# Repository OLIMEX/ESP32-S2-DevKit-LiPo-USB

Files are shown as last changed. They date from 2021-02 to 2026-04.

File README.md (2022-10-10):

# ESP32-S2-DevKit-LiPo-USB
ESP32-S2 development board with native USB-OTG, the hardware supports both USB host and USB device functionality, LiPo battery charger and step up for handheld battery operation.

Product page: https://www.olimex.com/Products/IoT/ESP32-S2/ESP32-S2-DevKit-Lipo-USB/open-source-hardware
## License
* Hardware is released under CERN OHL v1.2 license
* Software is released under GPL3 License
* Documentation is released under CC BY-SA 3.0

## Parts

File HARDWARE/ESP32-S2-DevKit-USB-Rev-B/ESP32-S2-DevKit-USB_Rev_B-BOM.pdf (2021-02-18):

13:08:49 | ESP32-S2-DevKit-USB_Rev_B-BOM 11/12/2020
Qty | Designation | Package | Designator
1 | 22R/R0402 | R0402 | R24
1 | 1k/R0402 | R0402 | R18
2 | 2.2k/R0402 | R0402 | R5,R6
5 | 10k/R0402 | R0402 | R1,R2,R9,R17,R22
1 | 13k/1%/R0402 | R0402 | R11
4 | 100k/R0402 | R0402 | R7,R10,R14,R16
1 | 130k/R0402 | R0402 | R3
1 | 220k/R0402 | R0402 | R8
2 | 470k/R0402 | R0402 | R13,R25
1 | 1M/R0402 | R0402 | R4
1 | 4.7M/R0402 | R0402 | R12
3 | 100nF/10V/10%/X7R/C0402 | C0402 | C12,C18,C20
1 | 1uF/10V/10%/X5R/C0603 | C0603 | C19
1 | 10uF/6.3V/20%/X5R/C0603 | C0603 | C1
5 | 22uF/6.3V/C0603 | C0603 | C3,C4,C10,C15,C16
1 | 47uF/6.3V/20%/X5R/C0805 | C0805 | C11
1 | 2.2uH/1.5A/DCR=72mR/20%/ 3.00x3.00x1.50mm/CD32(NR3015T2R2M) | CD32 | L2
1 | BAT54C(SOT23-3) | SOT23 | D4
4 | 1N5819S4/SOD123 | SOD-123_1C-2A_KA | D1,D2,D6,D3
1 | 1N4148W/SOD123 | SOD-123_1C-2A_KA | D5
1 | LED/YELLOW/0603 | LED_0603_KA | CHARG1
1 | WS2812S(5X5MM) | WS2812S(5x5MM) | RGB-LED1
3 | WPM2015-3/TR | SOT23 | FET1,FET3,FET4
1 | BSS138 | SOT23 | FET2
1 | BL4054B-42TPRN(SOT23-5) | SOT-23-5 | U1
1 | ESP32-S2-WROVER_and_WROOM (PCB,-I(IPEX))-Universal | ESP32-S2-xxx_MODULE | U4
1 | MT3608(SOT23-6) | SOT23-6 | U2
1 | SY6280AAC(SOT23-5) | SOT-23-5 | U3
1 | MCP1700T-3302E/MB | SOT89-3 | VR1
2 | HN1x21 | HN1x21 | EXT2,EXT1
1 | DW02S | DW02S | BAT1
1 | MISB-SWMM-5B-LF(USB_MICRO) | USB-MICRO | USB1
1 | WU06S | WU06S | ESP-PROG1
2 | IT-1185AU2-160G-G-TR | IT1185AU2_V2 | RST1,BUT1
3 | Opened | SJ_1 | BAT_SENS_E1, PWR_SENS_E1, 3.3V_E1
1 | Soldered | SJ_1 | LED_ENABLE1
1 | NA(Q32.768kHz/12.5pF/2P/SMD1206) | CM7V-T1A (Crystal_Package-1206_ 3.20x1.50x0.65mm) | Q4
2 | NA(22pF/50V/5%/COG/C0402) | C0402 | C21,C22
1 | NA(10M/R0402) | R0402 | R23
2 | NA(100nF/10V/10%/X7R/C0402) | C0402 | C23,C17

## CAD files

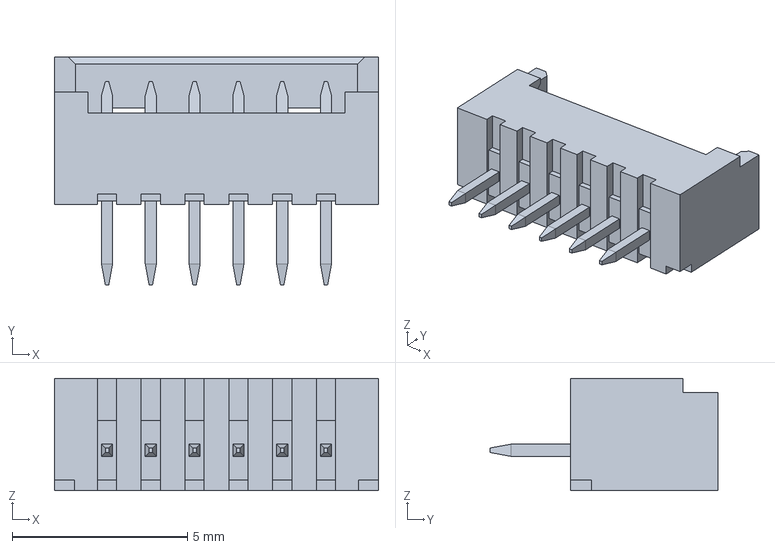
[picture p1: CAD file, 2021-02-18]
HARDWARE/ESP32-S2-DevKit-USB-Rev-B/3d/WU06S-Molex_PicoBlade_530470610_1x06_P1.25mm_Vertical.step
9.25 x 6.50 x 3.20 mm

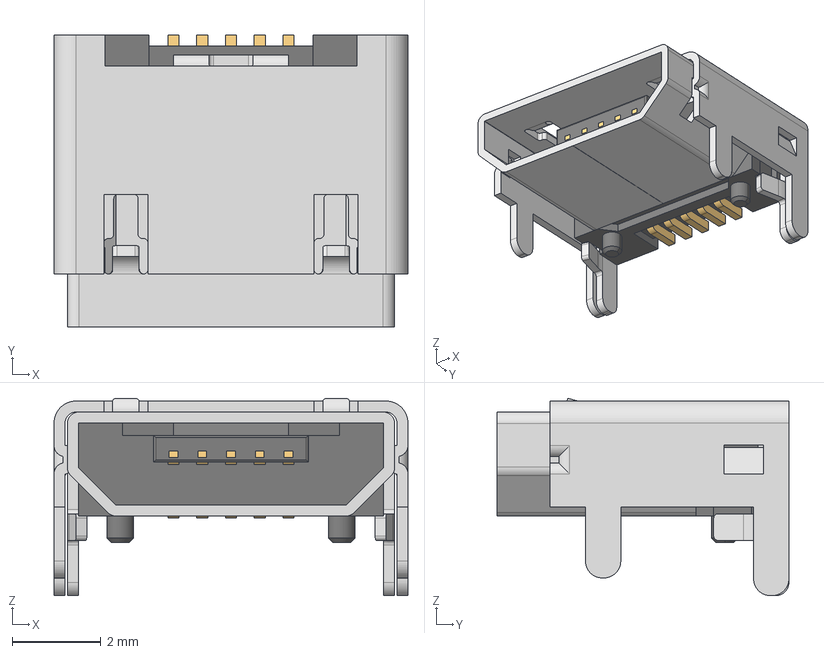
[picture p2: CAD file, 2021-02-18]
HARDWARE/ESP32-S2-DevKit-USB-Rev-B/3d/usb_micro_4p.stp
8.00 x 6.60 x 4.46 mm

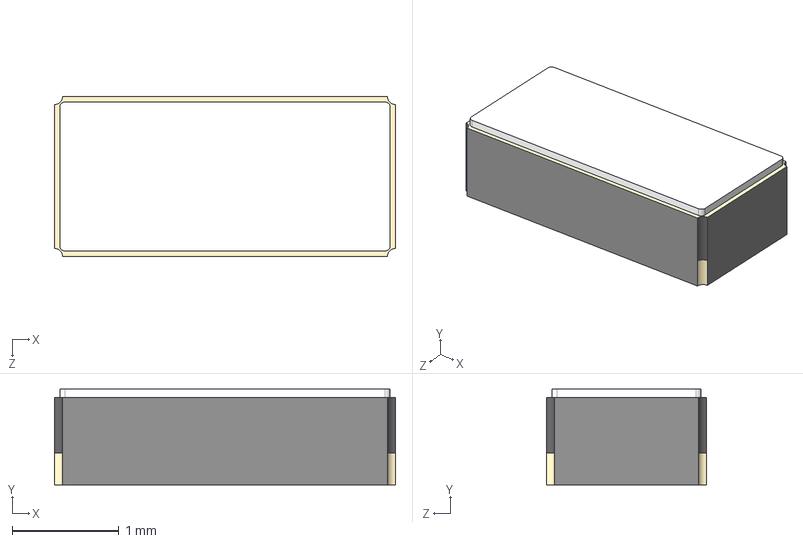
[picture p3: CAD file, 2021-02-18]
HARDWARE/ESP32-S2-DevKit-USB-Rev-B/3d/Q32.768kHz_12.5pF_2P_SMD1206---ECS-.327-12.5-34B-C-TR.STEP
3.20 x 0.9 x 1.50 mm

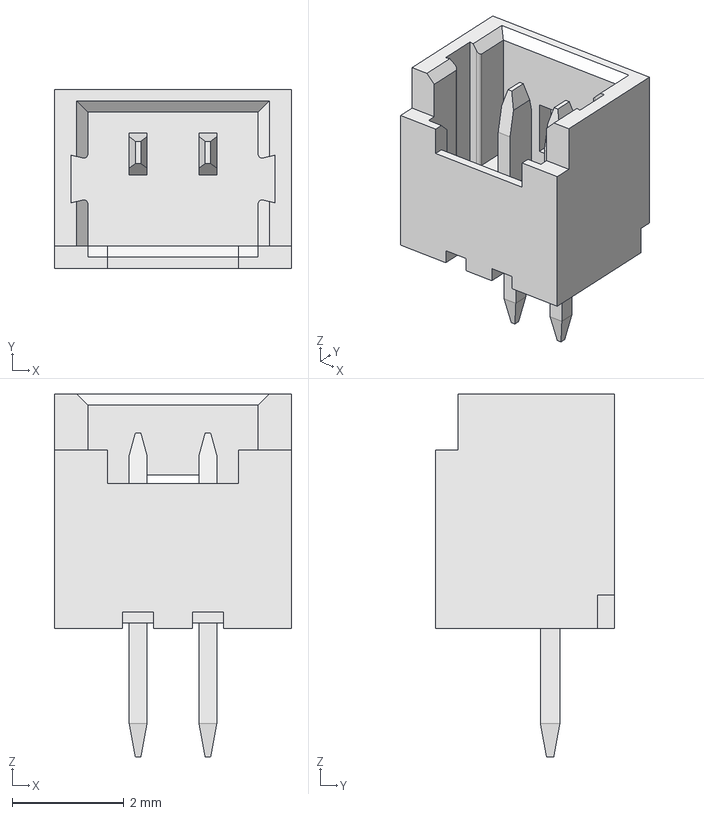
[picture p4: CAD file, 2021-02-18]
HARDWARE/ESP32-S2-DevKit-USB-Rev-B/3d/Molex_PicoBlade_530470210.step
4.25 x 3.20 x 6.50 mm

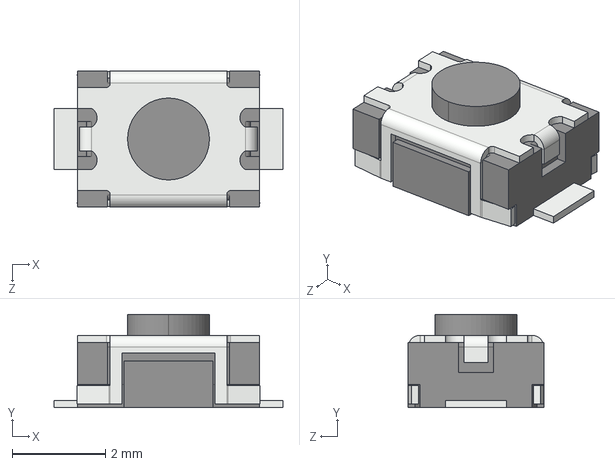
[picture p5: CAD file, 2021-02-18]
HARDWARE/ESP32-S2-DevKit-USB-Rev-B/3d/it1185.step
4.90 x 2.00 x 2.90 mm

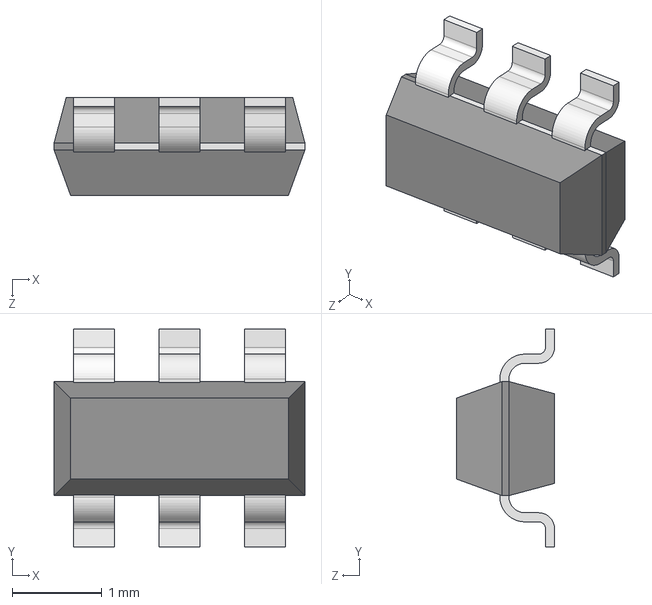
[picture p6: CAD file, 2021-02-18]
HARDWARE/ESP32-S2-DevKit-USB-Rev-B/3d/SOT-23-6.step
2.79 x 2.43 x 1.09 mm

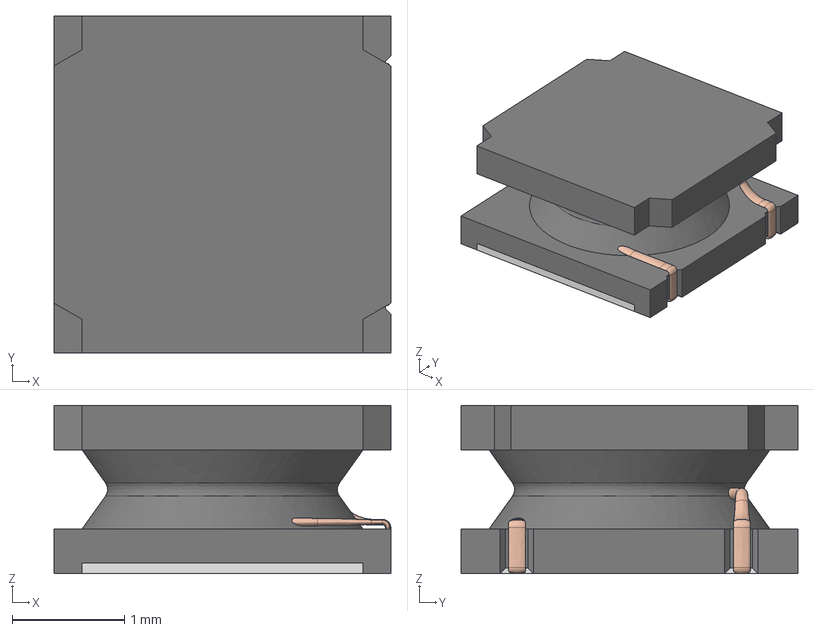
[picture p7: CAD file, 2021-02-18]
HARDWARE/ESP32-S2-DevKit-USB-Rev-B/3d/L-CD32_shielded.step
3.00 x 3.00 x 1.50 mm

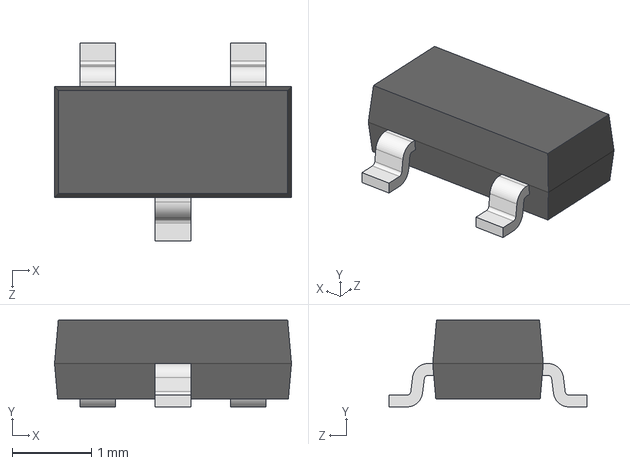
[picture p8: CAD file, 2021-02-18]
HARDWARE/ESP32-S2-DevKit-USB-Rev-B/3d/SOT-23.step
3.00 x 1.10 x 2.50 mm

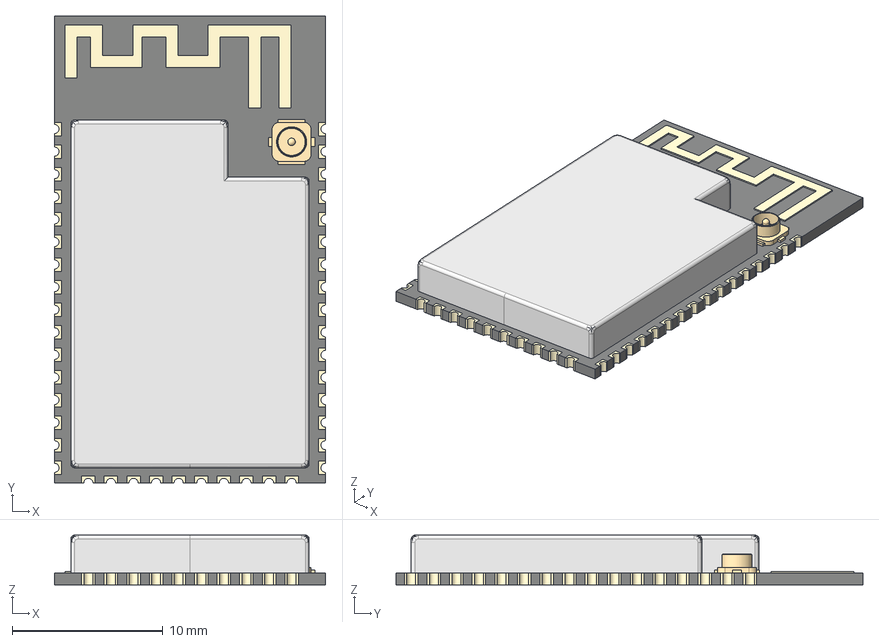
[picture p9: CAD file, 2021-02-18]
HARDWARE/ESP32-S2-DevKit-USB-Rev-B/3d/ESP32-S2-WROVER-I.STEP
18.0 x 31.0 x 3.30 mm
PCB
Castellations
Trace Antenna
UFL Connector
Can

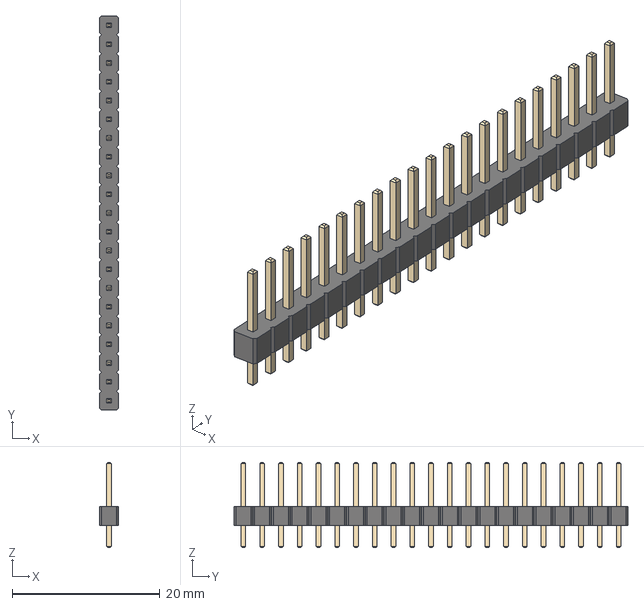
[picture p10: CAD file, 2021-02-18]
HARDWARE/ESP32-S2-DevKit-USB-Rev-B/3d/HN1x21-PinHeader_1x21_P2.54mm_Vertical.step
2.54 x 53.3 x 11.5 mm

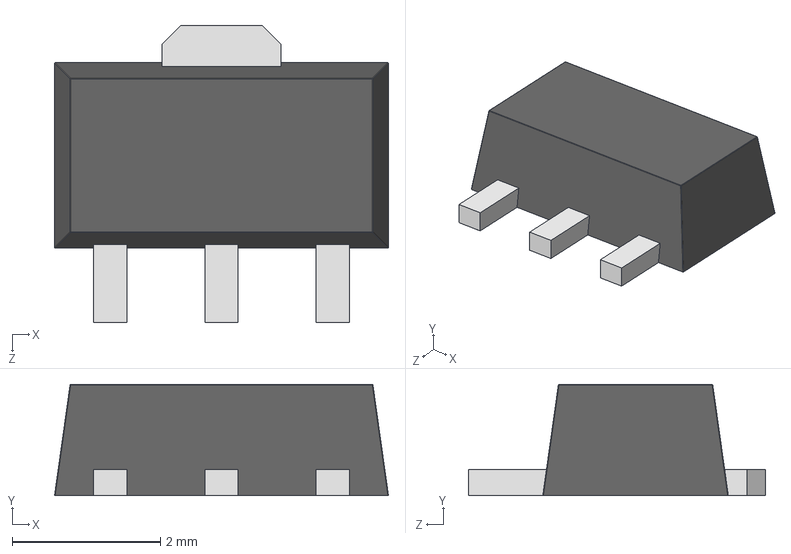
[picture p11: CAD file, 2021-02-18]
HARDWARE/ESP32-S2-DevKit-USB-Rev-B/3d/SOT-89.step
4.50 x 1.50 x 4.00 mm

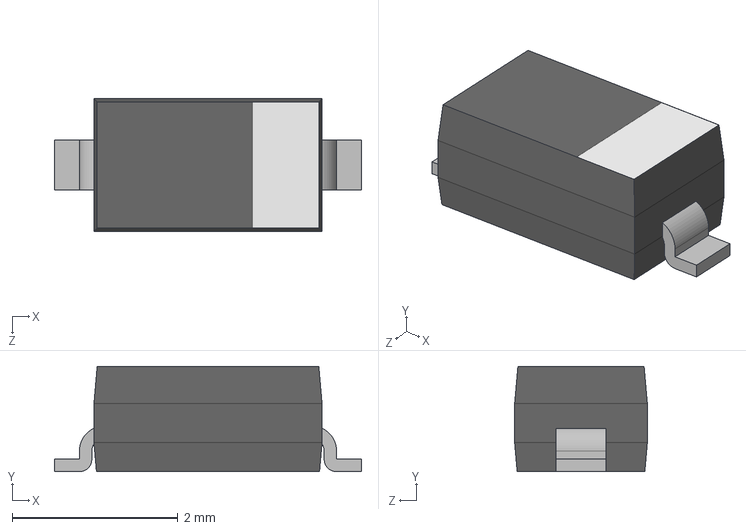
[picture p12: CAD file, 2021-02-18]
HARDWARE/ESP32-S2-DevKit-USB-Rev-B/3d/SOD123.step
3.70 x 1.27 x 1.60 mm

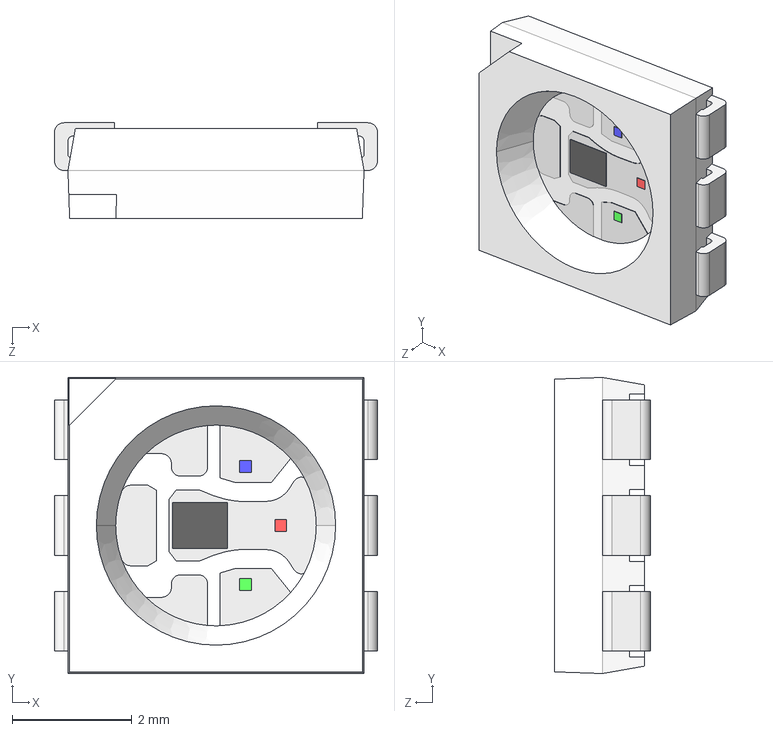
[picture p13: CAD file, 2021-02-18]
HARDWARE/ESP32-S2-DevKit-USB-Rev-B/3d/WS2812S.STEP
5.40 x 4.95 x 1.60 mm

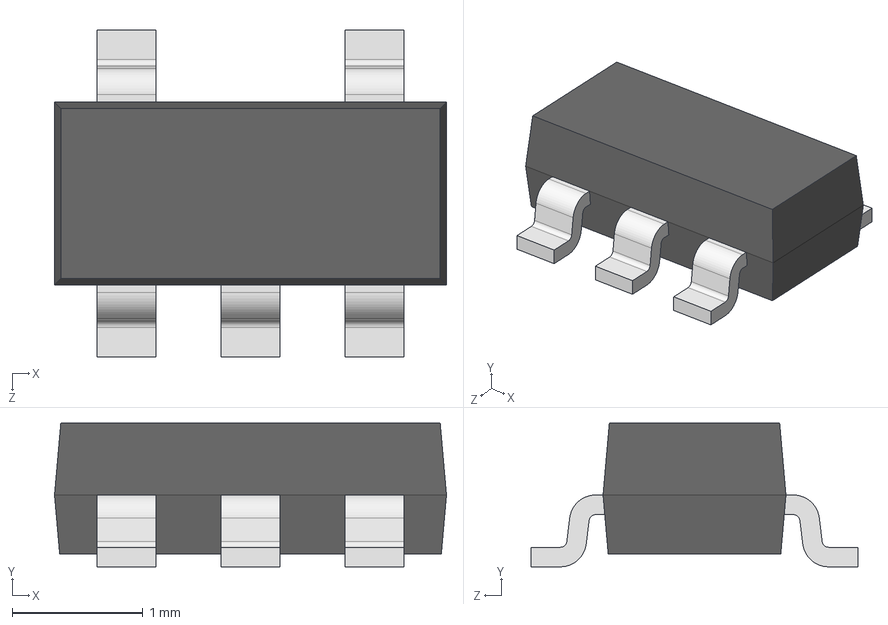
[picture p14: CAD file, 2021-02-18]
HARDWARE/ESP32-S2-DevKit-USB-Rev-B/3d/SOT-23-5.step
3.00 x 1.10 x 2.50 mm

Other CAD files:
HARDWARE/ESP32-S2-DevKit-USB-Rev-B/3d/BAT54.step

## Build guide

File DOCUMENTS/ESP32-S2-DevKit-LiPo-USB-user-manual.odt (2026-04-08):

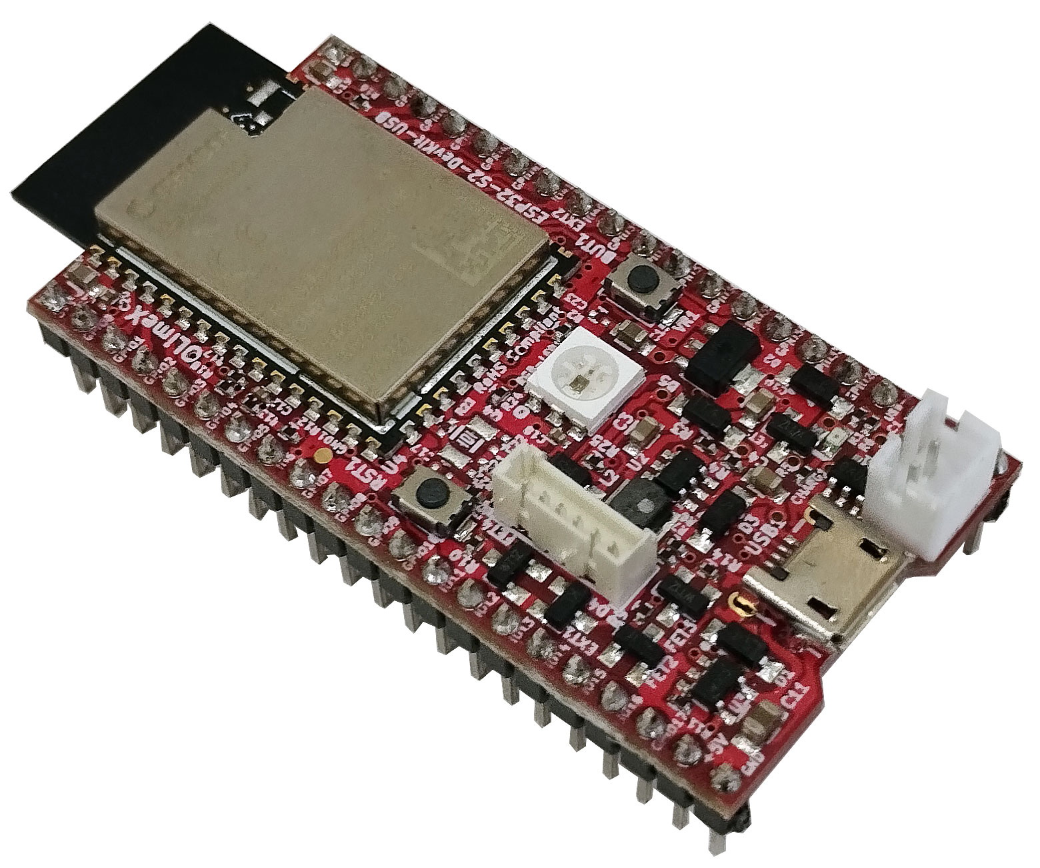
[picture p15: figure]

ESP32-S2-DevKit-LiPo-USB

User’s Manual

Document revision 1.1, April 2026 | www.olimex.com

# 1. What is ESP32-S2-DevKit-LiPo-USB

ESP32-S2-DevKit-LiPo-USB is an Open Source Hardware development board that incorporates an ESP32-S2 module. The ESP32-S2-DevKit-LiPo-USB board is designed and manufactured by Olimex, while the ESP32-S2 module is designed and manufactured by Espressif systems. The design is inspired by ESP32-S2-SAOLA-1 and has the same pinout, but adds Li-Po battery connector and charger. The board can operate on a Li-Po power when external power supply goes missing, allowing for handheld applications and increasing availability and reliability.

The ESP32-S2 modules are extremely popular WIFI modules due to their size, price, and very good documentation. The typical use is for WiFi enabled devices, especially in low power scenarios. ESP32-S2 supports low power modes including deep sleep that goes as low as 20uA.

Compared to ESP32, the ESP32-S2 has only a single core and misses the Ethernet and Bluetooth connectivity, but has much more GPIOs which were missing in ESP32.

The ESP32-S2-DevKit-LiPo-USB board has the following features:

- ESP32-S2-WROOM module or ESP32-S2-WROVER module
- RGB user LED
- User button, Reset button
- Micro USB-OTG connector for powering and programming; connected to the built-in USB interface
- Can work as USB host or USB device
- PROG connector
- Built-in LiPo battery charger
- LiPo battery connector
- Battery measurement and power detection circuits
- Two columns of pins with headers soldered for easy access to all the board’s GPIOs
- Low-power design for extended operation on battery
- PCB dimensions: (1.9×1.1)" ~ (4.8×2.8)cm
- Operating temperature: -40+85C

## 1.1 Difference between ESP32-S2-DevKit-LiPo-USB and ESP32-S2-DevKit-LiPo

ESP32-S2-DevKit-LiPo-USB uses the internal USB interface while ESP32-S2-DevKit-LiPo uses external CH340 adapter for the USB communication.

## 1.2 ESP32-S2-DevKit-LiPo-USB variants

The board has 4 variants:

- ESP32-S2-DevKit-LiPo-USB
- ESP32-S2-DevKit-LiPo-USB-EA
- ESP32-S2-WROVER-DevKit-LiPo-USB
- ESP32-S2-WROVER-DevKit-LiPo-USB-EA

All board variants work in the industrial temperature range (-40+85 degrees Celsius).

ESP32-S2-DevKit-LiPo-USB and ESP32-S2-DevKit-LiPo-USB-EA come with ESP32-WROOM-32E module;

ESP32-S2-WROVER-DevKit-LiPo-USB and ESP32-S2-WROVER-DevKit-LiPo-USB-EA come with ESP32-S2-WROVER-I-4MB;

Both variants with -EA suffix (ESP32-S2-DevKit-LiPo-USB-EA and ESP32-S2-WROVER-DevKit-LiPo-USB-EA) come with external 3dB antenna compatible with the module’s u.FL connector.

## 1.2 Board use requirements

You only need a fitting USB cable and a personal computer. The board requires USB micro connector. Usually only such cable is required:

https://www.olimex.com/Products/Components/Cables/USB-CABLE-A-MICRO-1.8M/

The computer needs software compatible with ESP32 modules. Most commonly used tools are ESP-IDF and Arduino IDE with ESP32 package. You can use ESP32-S2-DevKit-LiPo-USB with any software tool that supports the main ESP32 module.

Important: In order to program the board via the USB – remember to put the board in bootloader mode. This is done manually via the buttons – press and hold button BUT1, press and release button RST1, release button BUT1. After programming is done, remember to manually reset the board via RST1 button to leave bootloader mode. You need to enter bootloader mode every time before trying to program the board. Refer to chapter 7.

## 1.3 ESP32-S2-DevKit-LiPo-USB Open Source Licenses

ESP32-S2-DevKit-LiPo-USB is Open Source Hardware, listed in OSHWA.org here:

https://certification.oshwa.org/bg000107.html

The hardware files are released under CERN OSHW (https://github.com/OLIMEX/USB-gLINK/blob/master/cern_ohl_s_v2.pdf) license.

The software is released under GPL 3 license (https://github.com/OLIMEX/USB-gLINK/blob/master/LICENSE).

The documentation is released under CC BY-SA 3.0 (https://creativecommons.org/licenses/by-sa/3.0/) license.

# 2. General board layout

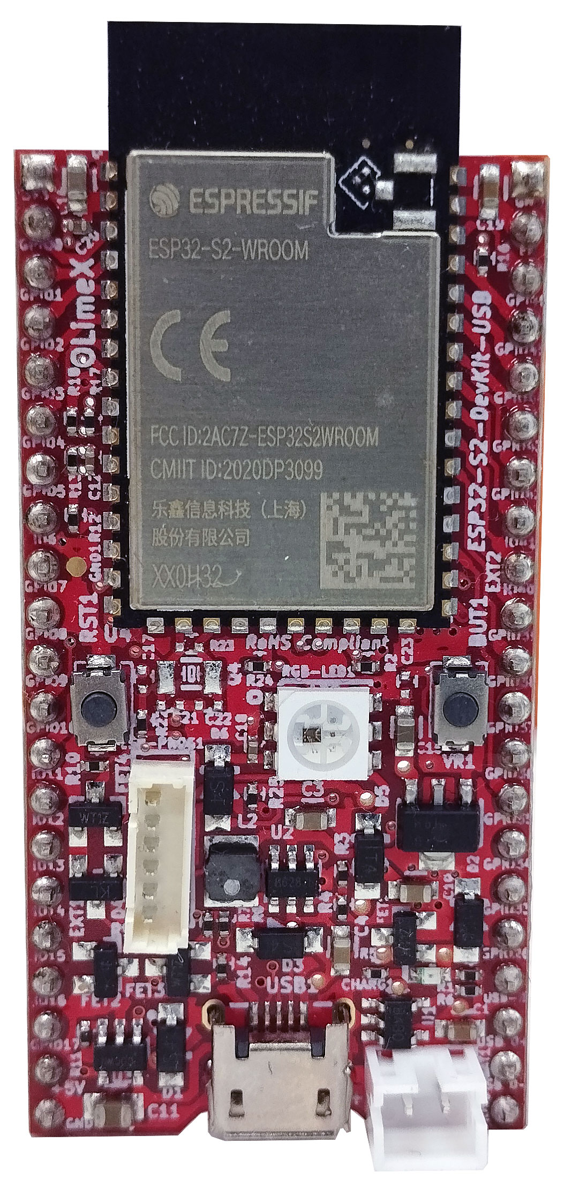
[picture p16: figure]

Ethernet commector

ESP32-S2 module

Li-Po battery conector

RGB user LED (GPIO18)

Power status LED

Micro USB

User button

BUT1 (GPIO0)

Reset button

RST1

Battery charger LED

ESP-PROG1 connector

# 3. Power supply and consumption

ESP32-S2-DevKit-LiPo-USB typically consumes around 50mA of current depending on the software. The board can consume much less using the power saving modes – down to around 20uA in deep sleep mode.

The absolute maximum power ESP32-S2-DevKit-LiPo-USB can draw from the power supply would be the determined by the maximum input of the regulator on the power input line. Of course, consider that on-board peripherals and the main module would use some of that current. The board uses low power regulator MCP1700T, it was chosen since it consumes only 1.5uA in power down mode. The downside is that it doesn’t provide a lot of current, up to a maximum of 500mA. Leave 100-150 for the ESP32-S2 module, you are left with 350-400mA for additional circuits.

There is an option to disable the RGB LED via PTH jumper at the bottom. The jumper is labelled “LED_ENABLE1”.

# 4. Schematics and dimensions

ESP32-S2-DevKit-LiPo-USB was designed with KiCAD (free and open-source CAD tool). ESP32-S2-DevKit-LiPo-USB schematics and sources can be found at GitHub here:

https://github.com/OLIMEX/ESP32-S2-DevKit-LiPo-USB/tree/main/HARDWARE

There are also PDF exports if you don’t want to install KiCAD.

# 5. ESP32-S2-DevKit-LiPo-USB pinout description

All pin names and functions are printed in white print at the bottom of the board. The board’s pinout can also be seen in the schematic’s bottom left corner.

The ESP32 chip has very good multiplexer so you can set the free GPIO pins for alternative functions via software means.

The PROG1 connector can be used for external USB serial converter like Olimex ESP-PROG-C (https://www.olimex.com/Products/IoT/Programmer/ESP-PROG/open-source-hardware).

The board has battery power sense and battery power measurement optional feature, that can be enabled by modifying the state jumpers PWR_SENS_E1 and BAT_SENS_E1. Close them (solder the pads together) to enable both functions, on pins GPIO7 and GPIO8.

The board also has an option for external quartz, there are pads provided (located just under the RST1 reset button).

# 6. Software installation

Espressif guide for Arduino IDE installation (https://docs.espressif.com/projects/arduino-esp32/en/latest/installing.html) – after installation – there is own entry for the board, it should be listed as OLIMEX ESP32-S2-DevKit-LiPo-USB in the board selection.

Olimex provides an Arduino example here:

https://github.com/OLIMEX/ESP32-S2-DevKit-LiPo-USB/blob/main/SOFTWARE/ARDUINO/ESP32-S2-DevKit-USB_RGB_LED/ESP32-S2-DevKit-USB_RGB_LED.ino

Espressif ESP-IDF installation (https://github.com/espressif/esp-idf)

Espressif guide for PlatformIO installation (https://docs.espressif.com/projects/arduino-esp32/en/latest/installing.html)

PlatformIO configs here: json and ini at GitHub (https://github.com/OLIMEX/ESP32-S2-DevKit-LiPo-USB/tree/main/SOFTWARE/PLATFORMIO)

There is esphome config here: yaml at GitHub (https://offnews.bg/razsledvane/atanas-rusev-e-chovekat-polzval-uslugite-na-tajnia-orakul-na-bivola-864388.html)

# 7. Step-by-step Arduino IDE installation

The instructions were made under Windows 10 but should be pretty similar for different operating systems.

## 7.1. Download and install Arduino IDE

If you still don’t have Arduino IDE, navigate to the following web-address to download it:

https://www.arduino.cc/en/software/

Download the version suitable for your operating system and install it (or extract it if you use the stand-alone version). After the installation is complete, launch the Arduino IDE application.

## 7.2. Install the ESP32-S2 support for Arduino IDE

7.2.1. Install Espressif Arduino-ESP32 stable release. To do so follow the detailed instructions here:

https://docs.espressif.com/projects/arduino-esp32/en/latest/installing.html

Short summary of what needs to be done:

- In Arduino IDE navigate to “File” → “Preferences” and in the filed that says “Additional Boards Manager URLs” append the following json link (copy-paste):

https://espressif.github.io/arduino-esp32/package_esp32_index.json

- Navigate to “Tools” → “Boards” → “Board Manager” and search for the esp32 platform. Install the latest version (3.0.4 at the time of writing this document).

If you encounter problems during the package installation make sure to check all details on the official guide from the link on the previous page.

7.2.2. Restart Arduino IDE and select the configuration for the board. Navigate to “Tools” → “Board” →under “ESP32 Arduino” tab. Find in the list “OLIMEX ESP32-S2-DevKit-Lipo-USB” and select it.

You can also change the properties (ESP32-WROOM and ESP32-WROVER require slightly different settings, since ESP32-WROVER has extra 8MB PSRAM). If you have WROVER version, enable PSRAM. Remember to have “Internal USB” as “Upload Mode:” selected and to select the proper COM port.

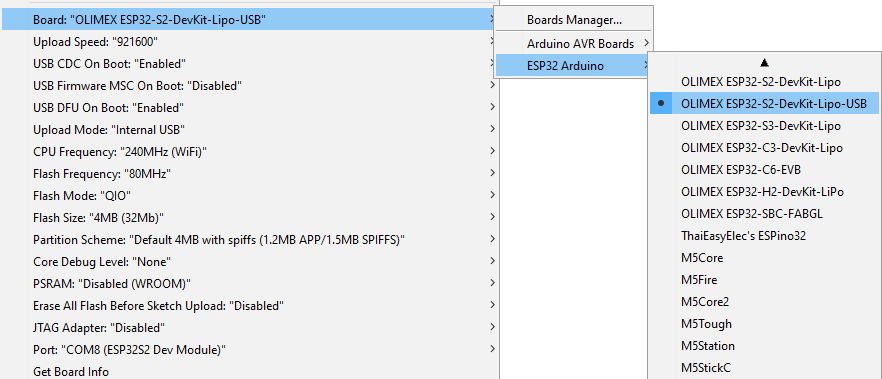
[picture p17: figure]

## 7.3. Put the board in bootloader mode

First connect the ESP32-S2 board to your computer via the micro USB connector using USB cable. In order to download code to ESP32-S2 you need to enter bootloader mode first. It is done by pressing and holding button BUT1, resetting the board by pressing RST1 button, then releasing button BUT1. The LED should stop blinking and new device would be visible in “Windows Device Manager”. In the “Windows Device Manager” you should be seeing 2 new devices. The one we need is called “USB Serial Device” (make sure to identify it, it will be different):

## 7.4. Upload a sketch

7.4.1. After you enter the bootloader mode as mentioned above, navigate to “Tools” → “Port…” select the COM of your device (make sure to identify it from “Windows Device Manager”):

7.4.2. Compile and upload your sketch – there is an example provided for the RGB LED at the end of this document;

7.4.3. If everything is alright the demo would be uploaded successfully, and error message that the board can’t be reset would be thrown. This is normal and expected:

You can disable reset after upload to not see the error.

7.4.4. Reset the board with button RST1 (without BUT1 being pressed) to switch from bootloader mode to execution mode – this will make the board run the uploaded sketch. Remember every time you want to re-program the board you need to re-enter bootloader mode!

## 7.5. RGB LED demo code

The demo is based on Adafruit demo. It requires to also install the Adafruit NeoPixel library from “Sketch” → “Include Library” → “Manage libraries...” search for Adafruit NeoPixel and install it.

You can find the demo code below or at the link here:

https://github.com/OLIMEX/ESP32-S2-DevKit-LiPo-USB/blob/main/SOFTWARE/ESP32-S2-DevKit-USB_RGB_LED.ino

/*

Board: ESP32-S2-DevKit-USB

Requires Adafruit NeoPixel library

*/

#include <Adafruit_NeoPixel.h> // go to Main Menu --> Sketch --> Include Library --> Manage libraries... search for Adafruit NeoPixel and install it (as of 17th September 2024 latest version is 1.12.3)

#define PIN 18

#define NUMPIXELS 1

#define PERIOD 10 //ms

Adafruit_NeoPixel pixels(NUMPIXELS, PIN, NEO_GRB + NEO_KHZ800);

int R=255, G=0, B=0;

void setup()

{

pixels.begin();

}

void loop ()

{

for (G=0; G<255; G++)

{

pixels.setPixelColor(0, pixels.Color(R, G, B));

pixels.show();

delay (PERIOD);

}

for (R=255; R>0; R--)

{

pixels.setPixelColor(0, pixels.Color(R, G, B));

pixels.show();

delay (PERIOD);

}

for (B=0; B<255; B++)

{

pixels.setPixelColor(0, pixels.Color(R, G, B));

pixels.show();

delay (PERIOD);

}

for (G=255; G>0; G--)

{

pixels.setPixelColor(0, pixels.Color(R, G, B));

pixels.show();

delay (PERIOD);

}

for (R=0; R<255; R++)

{

pixels.setPixelColor(0, pixels.Color(R, G, B));

pixels.show();

delay (PERIOD);

}

for (B=255; B>0; B--)

{

pixels.setPixelColor(0, pixels.Color(R, G, B));

pixels.show();

delay (PERIOD);

}

}

# 8. Document revision history

Revision 1.1 April 2026

- added links to yaml and json

Revision 1.0 September 2024

- initial release

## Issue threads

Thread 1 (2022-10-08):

Invalid Product link

pajasry, 2022-10-08:
Hi,
I bounced at your repository and found that the product link points to another product. It will be great if it could point to correct item.

https://github.com/OLIMEX/ESP32-S2-DevKit-LiPo-USB/blob/e5b7f0caae41b40c24599ce29c55959507c270ee/README.md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

TsvetanUsunov, 2022-10-10:
thanks for the note, this is fixed now

Closed 2022-10-10.

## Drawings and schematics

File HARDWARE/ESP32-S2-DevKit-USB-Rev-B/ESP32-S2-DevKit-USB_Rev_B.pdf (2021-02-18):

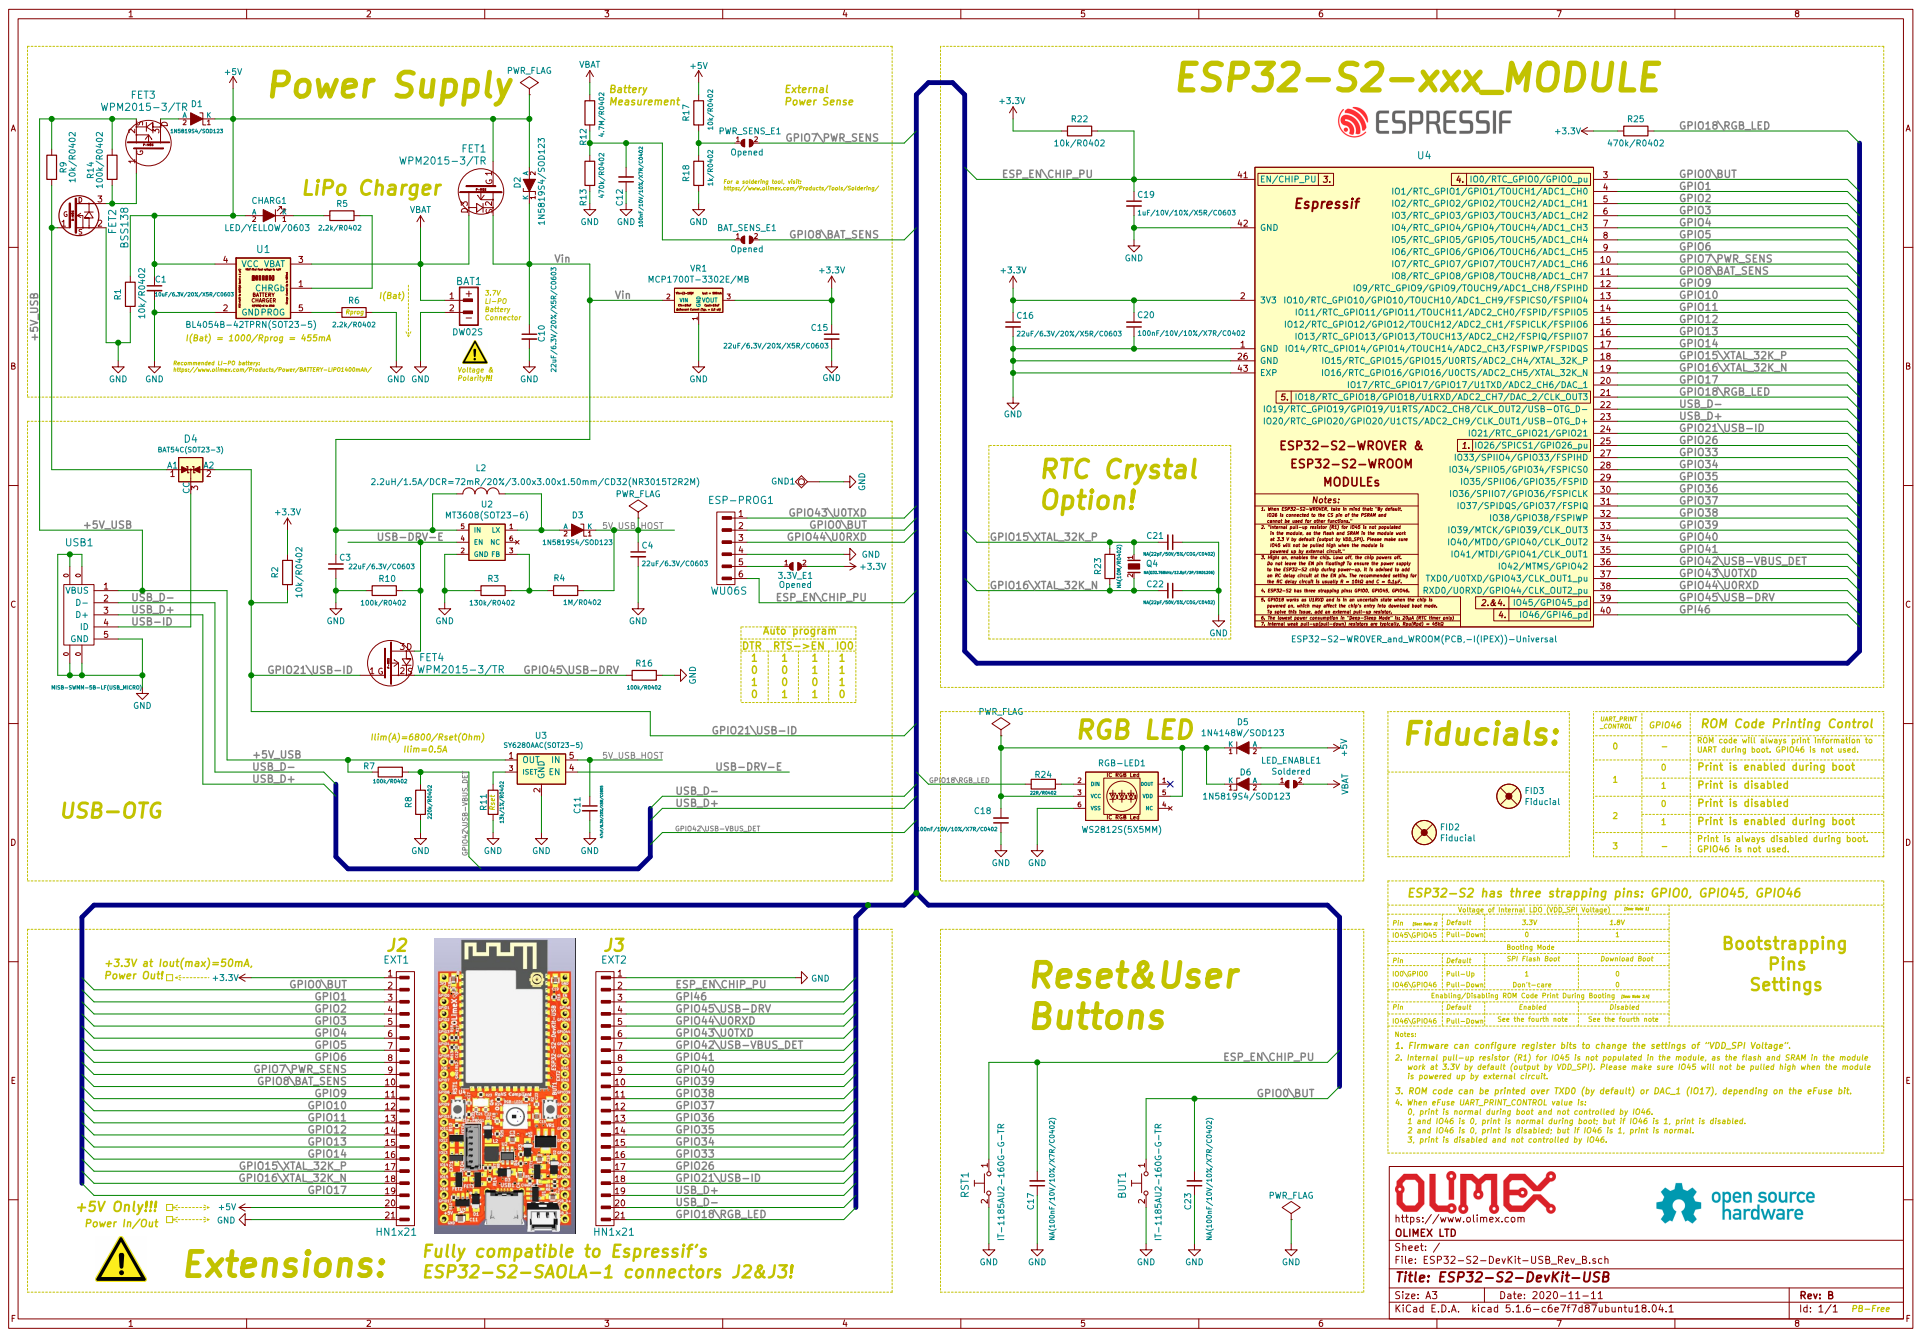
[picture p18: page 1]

Booting Mode LiPo Charger

For a soldering tool, visit: https://www.olimex.com/Products/Tools/Soldering/

1 2 Q4 R23 NA(Q32.768kHz/12.5pF/2P/SMD1206) NA(10M/R0402) Charge Current Up to 800mA R(PROG)=2 to 10k VBAT final float voltage to 4.2V VCC=4.5V to 6.5V(at least a 1 F) BATTERY CHARGER CHRGb 1 GND 2 VBAT 3 VCC 4 PROG 5 U1

to the ESP32-S2 chip during power-up, it is advised to add GND 1

Recommended LI-PO battery: https://www.olimex.com/Products/Power/BATTERY-LIPO1400mAh/

4. ESP32-S2 has three strapping pins: GPIO0, GPIO45, GPIO46. 5.

GPIO21\USB-ID GPIO41 GPIO21\USB-ID GPIO40

cannot be used for other functions." Do not leave the EN pin floating! To ensure the power supply ESP32-S2-WROOM

IO45 will not be pulled high when the module is MODULEs

IO26 is connected to the CS pin of the PSRAM and

in the module, as the flash and SRAM in the module work
5. GPIO18 works as U1RXD and is in an uncertain state when the chip is 6. The lowest power consumption in "Deep-Sleep Mode" is: 20A (RTC timer only) 7. Internal weak pull-up(pull-down) resistors are typically, Rpu(Rpd) = 45k an RC delay circuit at the EN pin. The recommended setting for at 3.3 V by default (output by VDD_SPI). Please make sure

powered on, which may affect the chips entry into download boot mode. powered up by external circuit."
3. High: on, enables the chip. Low: off, the chip powers off.

the RC delay circuit is usually R = 10k and C = 0.1F. To solve this issue, add an external pull-up resistor.

See the fourth note RGB LED

Ilim(A)=6800/Rset(Ohm)
- Fully compatible to Espressif's
Ilim=0.5A

0 Print is disabled Print is disabled

is powered up by external circuit. 1. Firmware can configure register bits to change the settings of VDD_SPI Voltage. Notes: ESP32-S2 has three strapping pins: GPIO0, GPIO45, GPIO46

3, print is disabled and not controlled by IO46. 3. ROM code can be printed over TXD0 (by default) or DAC_1 (IO17), depending on the eFuse bit. 2. Internal pull-up resistor (R1) for IO45 is not populated in the module, as the flash and SRAM in the module
work at 3.3V by default (output by VDD_SPI). Please make sure IO45 will not be pulled high when the module

0, print is normal during boot and not controlled by IO46.
1 and IO46 is 0, print is normal during boot; but if IO46 is 1, print is disabled.
2 and IO46 is 0, print is disabled; but if IO46 is 1, print is normal.

1 2BUT1 IT-1185AU2-160G-G-TR GND GND

File: ESP32-S2-DevKit-USB_Rev_B.sch Sheet: / OLIMEX LTD

Id: 1/1 Title: ESP32-S2-DevKit-USB

Rev: B | F Date: 2020-11-11 KiCad E.D.A. kicad 5.1.6-c6e7f7d87ubuntu18.04.1 Size: A3

PB-Free

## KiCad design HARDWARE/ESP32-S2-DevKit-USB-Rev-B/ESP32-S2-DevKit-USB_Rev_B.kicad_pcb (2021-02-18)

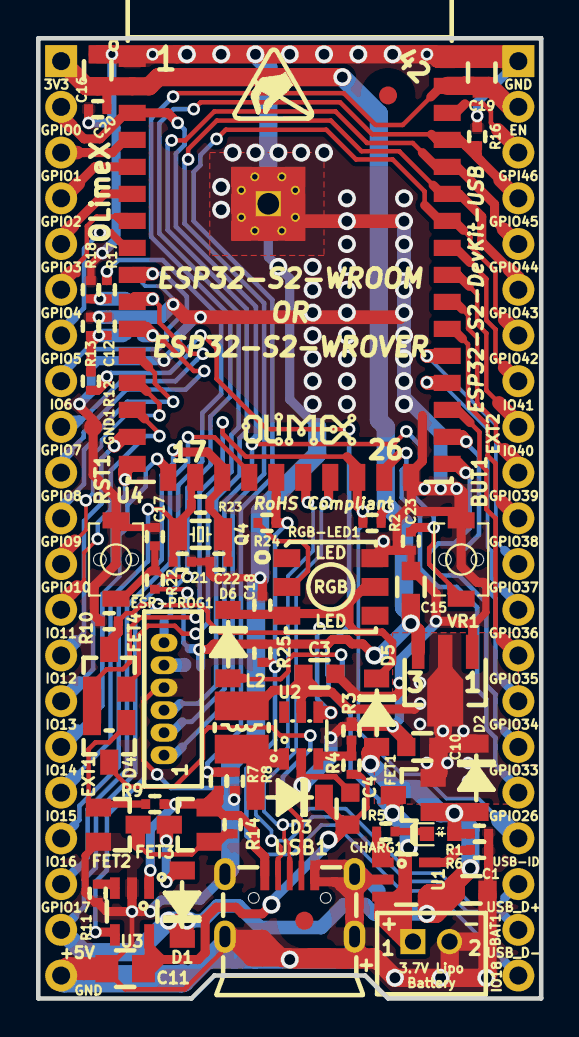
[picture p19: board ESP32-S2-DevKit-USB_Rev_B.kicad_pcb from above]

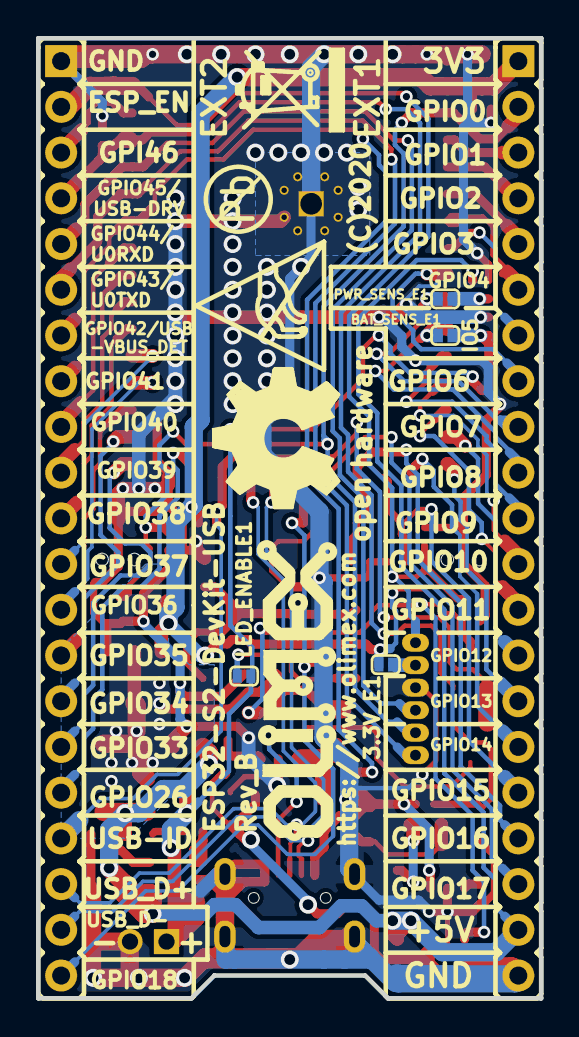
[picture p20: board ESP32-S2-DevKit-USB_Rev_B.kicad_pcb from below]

Board: 2 copper layers, 27.9 x 53.3 mm, 76 parts (11 on the bottom side), 62 nets.

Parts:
3.3V_E1: Opened; SJ_1_SMALLER
BAT1: DW02S; LIPO_BAT_VERTICAL_DW02S
BAT_SENS_E1: Opened; SJ_1_SMALLER
BUT1: IT-1185AU2-160G-G-TR; IT1185AU2_V2
C1: 10uF/6.3V/20%/X5R/C0603; C_0603_5MIL_DWS
C3, C4: 22uF/6.3V/C0603; C_0603_5MIL_DWS
C10, C15, C16: 22uF/6.3V/20%/X5R/C0603; C_0603_5MIL_DWS
C11: 47uF/6.3V/20%/X5R/C0805; C_0805_5MIL_DWS
C12, C18, C20: 100nF/10V/10%/X7R/C0402; C_0402_5MIL_DWS
C17, C23: NA(100nF/10V/10%/X7R/C0402); C_0402_5MIL_DWS
C19: 1uF/10V/10%/X5R/C0603; C_0603_5MIL_DWS
C21, C22: NA(22pF/50V/5%/COG/C0402); C_0402_5MIL_DWS
CHARG1: LED/YELLOW/0603; LED_0603_KA
D1, D2, D3, D6: 1N5819S4/SOD123; SOD-123_1C-2A_KA
D4: BAT54C(SOT23-3); SOT23-3
D5: 1N4148W/SOD123; SOD-123_1C-2A_KA
ESP-PROG1: WU06S
EXT1, EXT2: HN1x21
FET1, FET3, FET4: WPM2015-3/TR; SOT23
FET2: BSS138; SOT23
FID2, FID3: Fiducial; Fiducial1x3
GND1: TESTPAD; TESTPAD_40-ROUND
L2: 2.2uH/1.5A/DCR=72mR/20%/3.00x3.00x1.50mm/CD32(NR3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; CD32
LED_ENABLE1: Soldered; SJ_1_SMALLER
Logo_OSHW: LOGO_OPENHARDWARE_8x8
Olimex_Logo_Big: OLIMEX_LOGO_TB
Olimex_Logo_Small: LOGO_OLIMEX_80
PWR_SENS_E1: Opened; SJ_1_SMALLER
Q4: NA(Q32.768kHz/12.5pF/2P/SMD1206); CM7V-T1A(Crystal_Package-1206_3.20x1.50x0.65mm)
R1, R2, R9, R17, R22: 10k/R0402; R_0402_5MIL_DWS
R3: 130k/R0402; R_0402_5MIL_DWS
R4: 1M/R0402; R_0402_5MIL_DWS
R5, R6: 2.2k/R0402; R_0402_5MIL_DWS
R7, R10, R14, R16: 100k/R0402; R_0402_5MIL_DWS
R8: 220k/R0402; R_0402_5MIL_DWS
R11: 13k/1%/R0402; R_0402_5MIL_DWS
R12: 4.7M/R0402; R_0402_5MIL_DWS
R13, R25: 470k/R0402; R_0402_5MIL_DWS
R18: 1k/R0402; R_0402_5MIL_DWS
R23: NA(10M/R0402); R_0402_5MIL_DWS
R24: 22R/R0402; R_0402_5MIL_DWS
RGB-LED1: WS2812S(5X5MM); WS2812S(5x5MM)
RST1: IT-1185AU2-160G-G-TR; IT1185AU2_V2
Sign-Antistatic: LOGO_ANTISTATIC_1
Sign-Pb-Free: LOGO_PBFREE
Sign_Antistatic: Val**; LOGO_ANTISTATIC_SMALL_4.5mmX2.8mm
Sign_RecycleBin: LOGO_RECYCLEBIN_1
U1: BL4054B-42TPRN(SOT23-5); SOT-23-5
U2: MT3608(SOT23-6); SOT23-6
U3: SY6280AAC(SOT23-5); SOT-23-5
U4: ESP32-S2-WROVER_and_WROOM(PCB,-I(IPEX))-Universal; ESP32-S2-WROVER_MODULE
USB1: MISB-SWMM-5B-LF(USB_MICRO); USB-MICRO_MISB-SWMM-5B_LF
VR1: MCP1700T-3302E/MB; SOT89-3

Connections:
+3V3: 3.3V_E1.2, C15.1, C16.1, C20.2, EXT1.1, R2.2, R22.1, R25.1, U4.2, VR1.3
+5V: C1.1, CHARG1.2, D1.1, D2.2, D5.2, EXT1.20, FET1.1, R1.1, R17.1, U1.4
/5V_USB_HOST: C4.1, C11.1, D3.1, R4.1, U3.5
/+5V_USB: FET3.2, R7.2, R9.1, R14.1, U3.1, USB1.1
/ESP_EN\CHIP_PU: C17.2, C19.1, ESP-PROG1.6, EXT2.2, R22.2, RST1.1, U4.41
/GPI46: EXT2.3, U4.40
/GPIO0\BUT: BUT1.1, C23.2, ESP-PROG1.2, EXT1.2, U4.3
/GPIO1: EXT1.3, U4.4
/GPIO2: EXT1.4, U4.5
/GPIO3: EXT1.5, U4.6
/GPIO4: EXT1.6, U4.7
/GPIO5: EXT1.7, U4.8
/GPIO6: EXT1.8, U4.9
/GPIO7\PWR_SENS: EXT1.9, PWR_SENS_E1.2, U4.10
/GPIO8\BAT_SENS: BAT_SENS_E1.2, EXT1.10, U4.11
/GPIO9: EXT1.11, U4.12
/GPIO10: EXT1.12, U4.13
/GPIO11: EXT1.13, U4.14
/GPIO12: EXT1.14, U4.15
/GPIO13: EXT1.15, U4.16
/GPIO14: EXT1.16, U4.17
/GPIO15\XTAL_32K_P: C21.2, EXT1.17, Q4.1, R23.2, U4.18
/GPIO16\XTAL_32K_N: C22.2, EXT1.18, Q4.2, R23.1, U4.19
/GPIO17: EXT1.19, U4.20
/GPIO18\RGB_LED: EXT2.21, R24.1, R25.2, U4.21
/GPIO21\USB-ID: D4.2, EXT2.18, FET4.1, R2.1, U4.24
/GPIO26: EXT2.17, U4.25
/GPIO33: EXT2.16, U4.27
/GPIO34: EXT2.15, U4.28
/GPIO35: EXT2.14, U4.29
/GPIO36: EXT2.13, U4.30
/GPIO37: EXT2.12, U4.31
/GPIO38: EXT2.11, U4.32
/GPIO39: EXT2.10, U4.33
/GPIO40: EXT2.9, U4.34
/GPIO41: EXT2.8, U4.35
/GPIO42\USB-VBUS_DET: EXT2.7, R7.1, R8.2, U4.36
/GPIO43\U0TXD: ESP-PROG1.1, EXT2.6, U4.37
/GPIO44\U0RXD: ESP-PROG1.3, EXT2.5, U4.38
/GPIO45\USB-DRV: EXT2.4, FET4.2, R16.2, U4.39
/USB-DRV-E: FET4.3, R10.2, U2.4, U3.4
/USB-ID: D4.3, USB1.4
/USB_D+: EXT2.19, U4.23, USB1.3
/USB_D-: EXT2.20, U4.22, USB1.2
/Vin: C3.1, C10.1, D2.1, FET1.2, L2.1, U2.5, VR1.2
GND: BAT1.2, BUT1.2, C1.2, C3.2, C4.2, C10.2, C11.2, C12.1, C15.2, C16.2, C17.1, C18.1, C19.2, C20.1, C21.1, C22.1, C23.1, ESP-PROG1.4, EXT1.21, EXT2.1, FET2.2, GND1.1, R1.2, R3.1, R6.2, R8.1, R10.1, R11.1, R13.2, R16.1, R18.2, RGB-LED1.6, RST1.2, U1.2, U2.2, U3.2, U4.1, U4.26, U4.42, U4.43, USB1.0, USB1.5, VR1.1
unnamed: 3.3V_E1.1, ESP-PROG1.5
unnamed: BAT_SENS_E1.1, C12.2, R12.2, R13.1
unnamed: C18.2, D5.1, D6.1, RGB-LED1.3, RGB-LED1.5
unnamed: CHARG1.1, R5.1
unnamed: D1.2, FET3.3
unnamed: D3.2, L2.2, U2.1
unnamed: D4.1, FET2.1, R9.2
unnamed: D6.2, LED_ENABLE1.1
unnamed: FET2.3, FET3.1, R14.2
unnamed: PWR_SENS_E1.1, R17.2, R18.1
unnamed: R3.2, R4.2, U2.3
unnamed: R5.2, U1.1
unnamed: R6.1, U1.5
unnamed: R11.2, U3.3
unnamed: R24.2, RGB-LED1.2
VBAT: BAT1.1, FET1.3, LED_ENABLE1.2, R12.1, U1.3

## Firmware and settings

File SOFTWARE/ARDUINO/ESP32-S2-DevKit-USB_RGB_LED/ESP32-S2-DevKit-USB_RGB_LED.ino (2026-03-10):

#include <Arduino.h>
#include "driver/rmt_tx.h"
#include "driver/gpio.h"

#define LED_PIN 18
#define BUTTON_PIN 0
#define RMT_RESOLUTION_HZ 10000000

rmt_channel_handle_t tx_chan = NULL;
rmt_encoder_handle_t encoder = NULL;

bool lastButton = HIGH;
uint8_t mode = 0;

uint32_t lastAnim = 0;
uint8_t rainbow = 0;

const char* modeDescription[] = {
  "Mode 0: LED OFF",
  "Mode 1: Red LED always ON",
  "Mode 2: Green LED always ON",
  "Mode 3: Blue LED always ON",
  "Mode 4: Rainbow animation"
};

void ws2812_init()
{
  rmt_tx_channel_config_t tx_config = {
      .gpio_num = (gpio_num_t)LED_PIN,
      .clk_src = RMT_CLK_SRC_DEFAULT,
      .resolution_hz = RMT_RESOLUTION_HZ,
      .mem_block_symbols = 64,
      .trans_queue_depth = 4
  };

  rmt_new_tx_channel(&tx_config, &tx_chan);

  rmt_bytes_encoder_config_t bytes_config;

  bytes_config.bit0.duration0 = 4;
  bytes_config.bit0.level0 = 1;
  bytes_config.bit0.duration1 = 8;
  bytes_config.bit0.level1 = 0;

  bytes_config.bit1.duration0 = 8;
  bytes_config.bit1.level0 = 1;
  bytes_config.bit1.duration1 = 4;
  bytes_config.bit1.level1 = 0;

  bytes_config.flags.msb_first = 1;

  rmt_new_bytes_encoder(&bytes_config, &encoder);

  rmt_enable(tx_chan);
}

void ws2812_write(uint8_t r, uint8_t g, uint8_t b)
{
  uint8_t data[3] = {g,r,b};

  rmt_transmit_config_t tx_config = {0};

  rmt_transmit(tx_chan, encoder, data, sizeof(data), &tx_config);
  rmt_tx_wait_all_done(tx_chan, portMAX_DELAY);
}

void rainbowStep()
{
  uint8_t r,g,b;
  uint8_t pos = rainbow;

  if(pos < 85) {
    r = pos * 3;
    g = 255 - pos * 3;
    b = 0;
  }
  else if(pos < 170) {
    pos -= 85;
    r = 255 - pos * 3;
    g = 0;
    b = pos * 3;
  }
  else {
    pos -= 170;
    r = 0;
    g = pos * 3;
    b = 255 - pos * 3;
  }

  ws2812_write(r,g,b);
  rainbow++;
}

void setup()
{
  Serial.begin(115200);

  pinMode(BUTTON_PIN, INPUT_PULLUP);

  ws2812_init();

  Serial.println();
  Serial.println("ESP32-S2 RGB LED Demo");
  Serial.println("Press USER button to change LED mode");
  Serial.println(modeDescription[mode]);
}

void loop()
{
  bool button = digitalRead(BUTTON_PIN);

  if(lastButton == HIGH && button == LOW)
  {
    mode++;
    if(mode > 4) mode = 0;

    Serial.println();
    Serial.print("Button pressed -> ");
    Serial.println(modeDescription[mode]);
  }

  lastButton = button;

  if(mode == 0) ws2812_write(0,0,0);
  if(mode == 1) ws2812_write(40,0,0);
  if(mode == 2) ws2812_write(0,40,0);
  if(mode == 3) ws2812_write(0,0,40);

  if(mode == 4)
  {
    if(millis() - lastAnim > 30)
    {
      rainbowStep();
      lastAnim = millis();
    }
  }
}

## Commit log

2021-02-18 initial upload
    [BAT54.step, ESP32-S2-DevKit-USB_Rev_B-BOM.ods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]
2024-09-18 Update
    Added user's manual, removed outdated Arduino IDE guide
2026-03-10 Update
    Added new Arduino examples

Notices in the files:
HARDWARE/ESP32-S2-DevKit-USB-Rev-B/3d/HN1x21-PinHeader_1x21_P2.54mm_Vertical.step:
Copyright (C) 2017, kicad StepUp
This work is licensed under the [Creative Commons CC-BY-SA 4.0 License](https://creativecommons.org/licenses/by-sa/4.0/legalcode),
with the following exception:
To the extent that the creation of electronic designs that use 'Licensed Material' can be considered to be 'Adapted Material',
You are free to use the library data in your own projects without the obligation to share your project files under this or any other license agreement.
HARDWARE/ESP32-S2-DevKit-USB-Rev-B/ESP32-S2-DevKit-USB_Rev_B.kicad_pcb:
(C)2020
